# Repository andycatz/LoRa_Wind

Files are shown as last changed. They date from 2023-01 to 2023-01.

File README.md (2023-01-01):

# LoRa_Wind
Wind Sensor with LoRa transmitter
Code is for the PIC18LF46K22 microcontroller.
Data is transmitted as 50 bytes to the base receiver (Raspberry pi) running WSP2.py code.
See the file "Sensor Data Formats New Formats from 18th Sept 2021 onwards.xlsx".
Wind speed is derived by counting pulses, 2 per rotation assumed from sensor.
Gust is calculated by storing pulse count every 2 seconds.  After one minute, the highest count is stored for transmission as the gust speed.
The average speed is transmitted as the total pulse count for 1 minute.
All calibration is done at the receiver (Raspberry pi).
This module is powered from 2 x C size batteries which should last a good 2 to 3 years.
Make sure the battery housing is in an accessible location for battery change.
Alkaline batteries are recommended due to the wider temperature range of operation.
STL files are provided for the battery/transmitter enclosure.

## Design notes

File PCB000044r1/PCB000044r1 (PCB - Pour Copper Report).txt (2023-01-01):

Pour Copper Report
------------------

Report Written:     Saturday, January 29, 2022
Project Path:       D:\Documents\Design Spark\000000's\PCB000044r1\PCB000044r1.prj
Design Path:        D:\Documents\Design Spark\000000's\PCB000044r1\PCB000044r1.pcb
Design Title:       
Created:            03/01/2022 11:23:58
Last Saved:         29/01/2022 21:23:30
Editing Time:       291 min
Units:              mm (precision 1)

End Of Report.

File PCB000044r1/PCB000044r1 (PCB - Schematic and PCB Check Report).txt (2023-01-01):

Schematic and PCB Check Report
------------------------------

Report Written:     Saturday, January 29, 2022
Project Path:       D:\Documents\Design Spark\000000's\PCB000044r1\PCB000044r1.prj
Design Path:        D:\Documents\Design Spark\000000's\PCB000044r1\PCB000044r1.pcb
Design Title:       
Created:            03/01/2022 11:23:58
Last Saved:         29/01/2022 20:46:41
Editing Time:       260 min
Units:              mm (precision 1)

Checking integrity of Schematic and Pcb designs in project "PCB000044r1"
========================================================================

End Of Report.

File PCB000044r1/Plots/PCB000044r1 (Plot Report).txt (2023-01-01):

Plot Report
-----------

Report Written:     Sunday, January 30, 2022
Project Path:       D:\Documents\Design Spark\000000's\PCB000044r1\PCB000044r1.prj
Design Path:        D:\Documents\Design Spark\000000's\PCB000044r1\PCB000044r1.pcb
Design Title:       
Created:            03/01/2022 11:23:58
Last Saved:         29/01/2022 21:34:18
Editing Time:       304 min
Units:              mm (precision 3)

Device Settings
===============

Drill Settings
==============

    Excellon Format 2
    Format 3.5 absolute in mm.
    Zero suppression Leading

Plots Output
============

    Plot Job: "D:\Documents\Design Spark\000000's\PCB000044r1\PCB000044r1.mop"

NC Drill Output
===============

D:\Documents\Design Spark\000000's\PCB000044r1\Plots\PCB000044r1 - NC Drill Data - [Through Hole].nc

    Output:
    -----------------------------
    Plated Round Drill Holes
    Unplated Round Drill Holes
    Plated Slots
    Unplated Slots

    Tool  Size       Count   ID
    ----------------------------------
    T001  0.60000 mm 77    E
    T002  0.60960 mm 16    B
    T003  0.80000 mm 1     J
    T004  0.81280 mm 14    L
    T005  1.00000 mm 26    D
    T006  1.20000 mm 3     C
    T007  1.49860 mm 7     O
    T008  3.20000 mm 4     F
    ----------------------------------
    Total            148
    ----------------------------------

End Of Report.

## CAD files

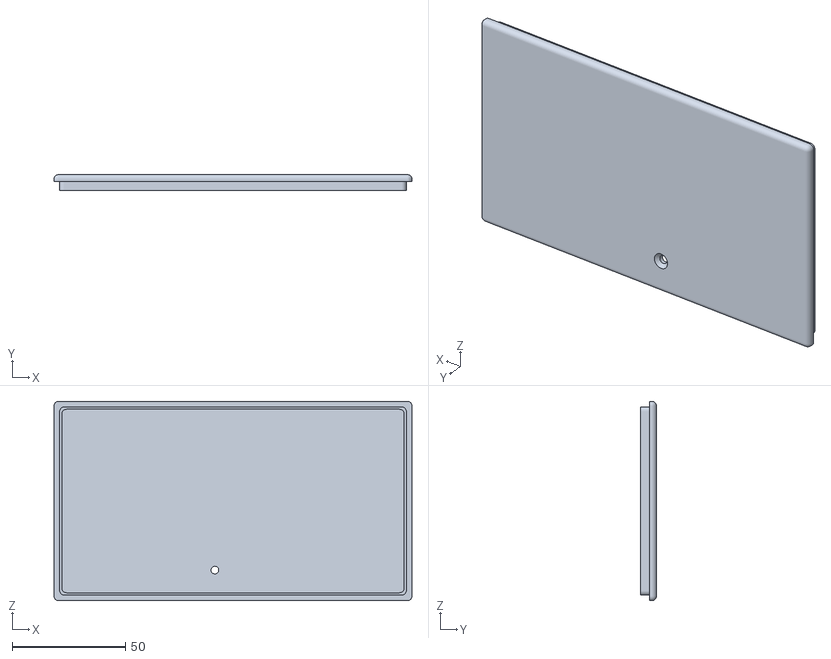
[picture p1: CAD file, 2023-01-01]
Wind Sensor Enclosure/Cover.stl
158.0 x 7.00 x 88.0

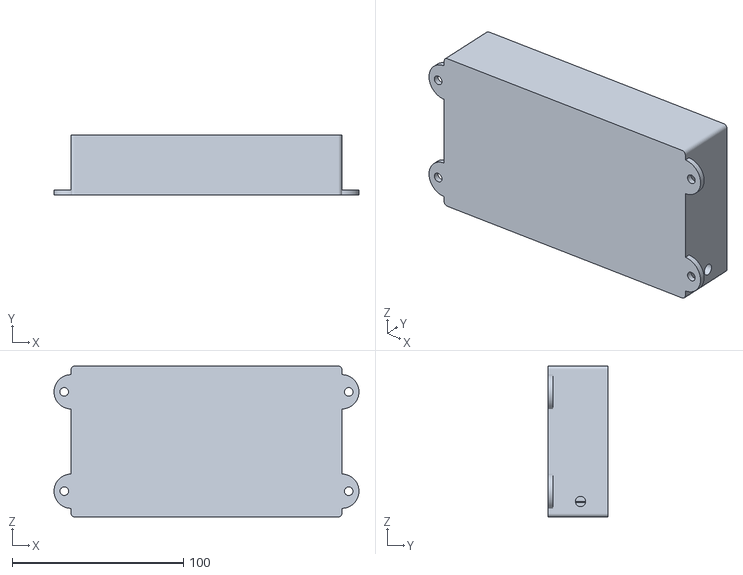
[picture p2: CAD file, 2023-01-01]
Wind Sensor Enclosure/Box.stl
178.0 x 35.0 x 88.0

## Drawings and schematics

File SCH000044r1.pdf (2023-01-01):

A | B | C | D | E | F

2

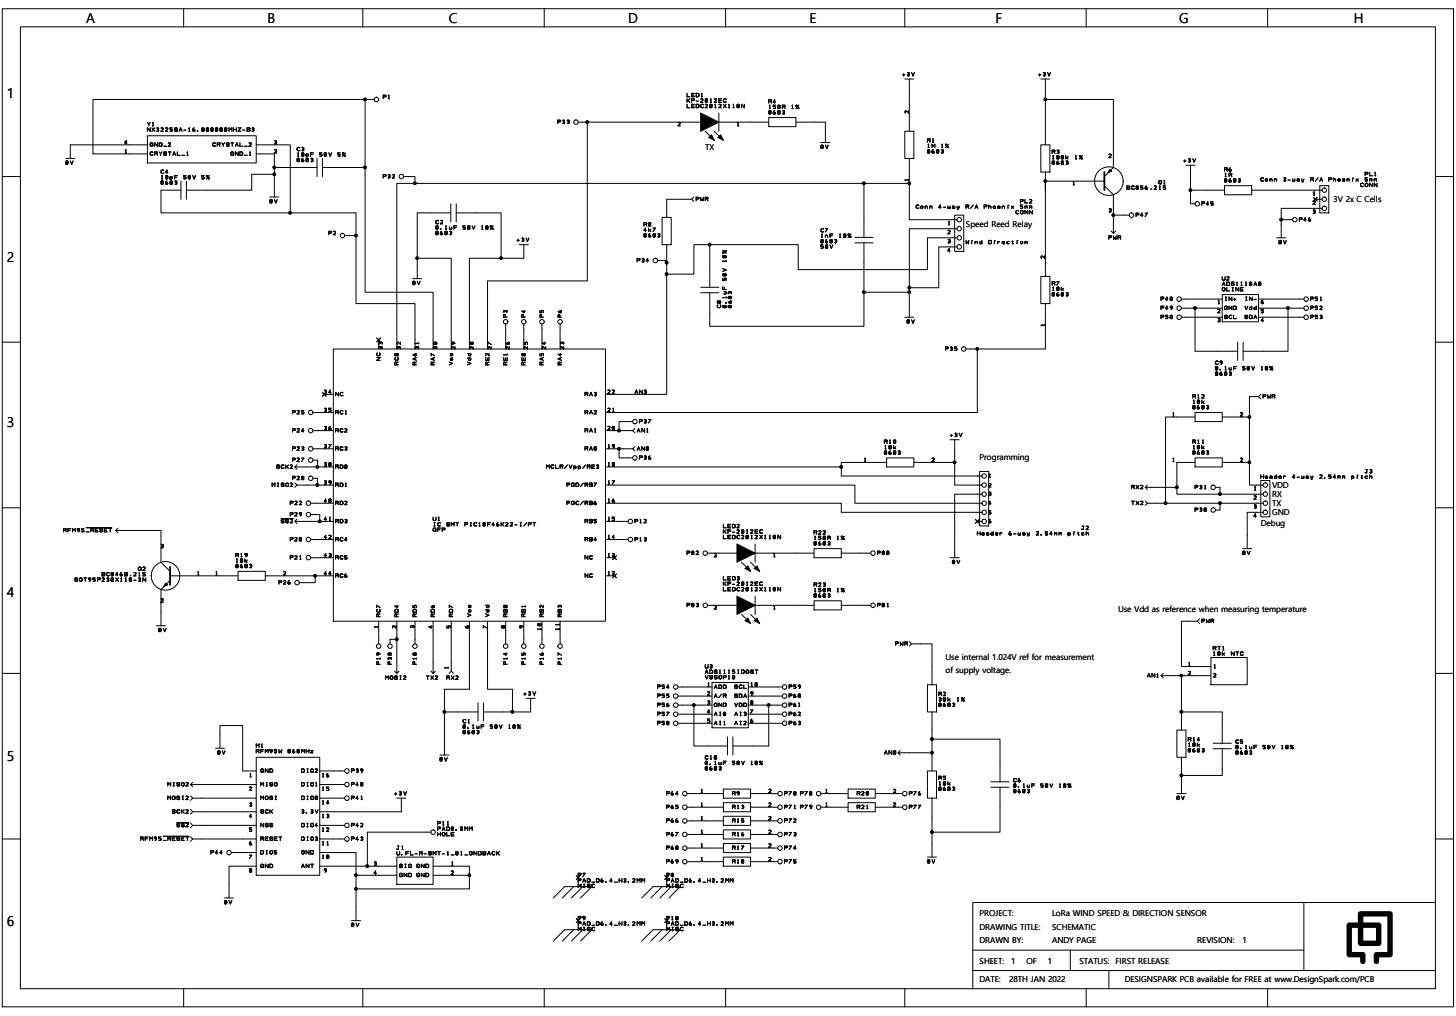
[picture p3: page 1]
28TH JAN 2022; Programming; Debug; VDD; GND; 3V 2x C Cells; PROJECT: DRAWING TITLE: DRAWN BY:; SHEET:; DATE:; REVISION:

Speed Reed Relay

Use Vdd as reference when measuring temperature

Use internal 1.024V ref for measurement
of supply voltage.

LoRa WIND SPEED & DIRECTION SENSOR
SCHEMATIC
ANDY PAGE
STATUS:

FIRST RELEASE
DESIGNSPARK PCB available for FREE at www.DesignSpark.com/PCB

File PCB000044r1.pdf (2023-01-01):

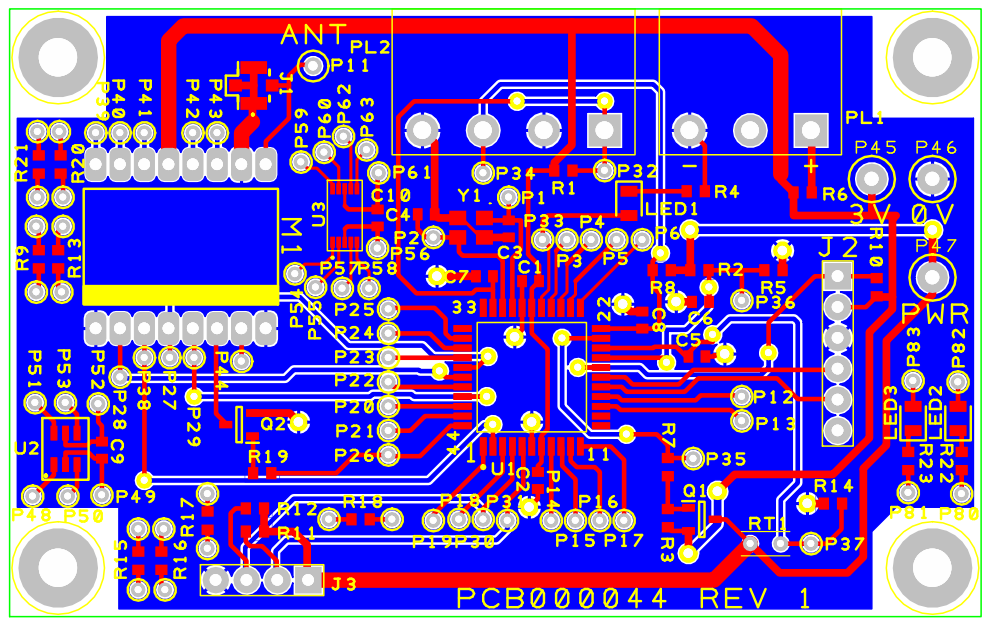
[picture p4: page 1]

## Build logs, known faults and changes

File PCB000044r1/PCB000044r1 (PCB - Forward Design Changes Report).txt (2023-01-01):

Forward Design Changes Report
-----------------------------

Report Written:     Saturday, January 29, 2022
Project Path:       D:\Documents\Design Spark\000000's\PCB000044r1\PCB000044r1.prj
Design Path:        D:\Documents\Design Spark\000000's\PCB000044r1\PCB000044r1.pcb
Design Title:       
Created:            03/01/2022 11:23:58
Last Saved:         29/01/2022 20:46:41
Editing Time:       260 min
Units:              mm (precision 1)

Added net "N0074".
Added net "N0075".
Added net "N0076".
Added net "N0077".
Added net "N0079".
Added net "N0080".
Added net "N0081".
Added net "N0082".
Added net "N0084".
Added net "N0085".
Added net "N0086".
Added net "N0087".
Added net "N0088".
Added net "N0089".
Added net "N0090".
Added net "N0091".
Added net "N0092".
Added net "N0093".
Added net "N0094".
Added net "N0095".
Added net "N0096".
Added net "N0097".
Added net "N0098".
Added net "N0099".
Added net "N0100".
Added net "N0101".
Added net "N0102".
Added net "N0103".
Added net "N0104".
Added net "N0105".
Added net "N0106".
Added net "N0107".

Added component reference "U3" of component "ADS1115IDGST", package "VSSOP10".
Added component reference "C10" of component "C0603C104K5RACTU", package "CAPC1608X95N".
Added value "Value=0.1uF 50V 10%" to component reference "C10".
Added value "Package=0603" to component reference "C10".
Added component reference "P54" of component "PAD0.6MM", package "PAD".
Added component reference "P55" of component "PAD0.6MM", package "PAD".
Added component reference "P56" of component "PAD0.6MM", package "PAD".
Added component reference "P57" of component "PAD0.6MM", package "PAD".
Added component reference "P58" of component "PAD0.6MM", package "PAD".
Added component reference "P59" of component "PAD0.6MM", package "PAD".
Added component reference "P60" of component "PAD0.6MM", package "PAD".
Added component reference "P61" of component "PAD0.6MM", package "PAD".
Added component reference "P62" of component "PAD0.6MM", package "PAD".
Added component reference "P63" of component "PAD0.6MM", package "PAD".
Added component reference "R9" of component "CRCW060310K0FKEAHP", package "RESC1608X50N".
Added component reference "R13" of component "CRCW060310K0FKEAHP", package "RESC1608X50N".
Added component reference "R15" of component "CRCW060310K0FKEAHP", package "RESC1608X50N".
Added component reference "R16" of component "CRCW060310K0FKEAHP", package "RESC1608X50N".
Added component reference "R17" of component "CRCW060310K0FKEAHP", package "RESC1608X50N".
Added component reference "R18" of component "CRCW060310K0FKEAHP", package "RESC1608X50N".
Added component reference "R20" of component "CRCW060310K0FKEAHP", package "RESC1608X50N".
Added component reference "R21" of component "CRCW060310K0FKEAHP", package "RESC1608X50N".
Added component reference "P64" of component "PAD0.6MM", package "PAD".
Added component reference "P65" of component "PAD0.6MM", package "PAD".
Added component reference "P66" of component "PAD0.6MM", package "PAD".
Added component reference "P67" of component "PAD0.6MM", package "PAD".
Added component reference "P68" of component "PAD0.6MM", package "PAD".
Added component reference "P69" of component "PAD0.6MM", package "PAD".
Added component reference "P70" of component "PAD0.6MM", package "PAD".
Added component reference "P71" of component "PAD0.6MM", package "PAD".
Added component reference "P72" of component "PAD0.6MM", package "PAD".
Added component reference "P73" of component "PAD0.6MM", package "PAD".
Added component reference "P74" of component "PAD0.6MM", package "PAD".
Added component reference "P75" of component "PAD0.6MM", package "PAD".
Added component reference "P76" of component "PAD0.6MM", package "PAD".
Added component reference "P77" of component "PAD0.6MM", package "PAD".
Added component reference "P78" of component "PAD0.6MM", package "PAD".
Added component reference "P79" of component "PAD0.6MM", package "PAD".
Added component reference "LED2" of component "KP-2012EC", package "LEDC2012X110N".
Added component reference "LED3" of component "KP-2012EC", package "LEDC2012X110N".
Added component reference "R22" of component "CRCW0603150RFKTA", package "RESC1608X50N".
Added value "Value=150R 1%" to component reference "R22".
Added value "Package=0603" to component reference "R22".
Added component reference "R23" of component "CRCW0603150RFKTA", package "RESC1608X50N".
Added value "Value=150R 1%" to component reference "R23".
Added value "Package=0603" to component reference "R23".
Added component reference "P80" of component "PAD0.6MM", package "PAD".
Added component reference "P81" of component "PAD0.6MM", package "PAD".
Added component reference "P82" of component "PAD0.6MM", package "PAD".
Added component reference "P83" of component "PAD0.6MM", package "PAD".

Connected pin "U3.1" to net "N0076".
Connected pin "U3.2" to net "N0077".
Connected pin "U3.3" to net "N0075".
Connected pin "U3.4" to net "N0079".
Connected pin "U3.5" to net "N0080".
Connected pin "U3.6" to net "N0085".
Connected pin "U3.7" to net "N0084".
Connected pin "U3.8" to net "N0074".
Connected pin "U3.9" to net "N0082".
Connected pin "U3.10" to net "N0081".
Connected pin "C10.1" to net "N0075".
Connected pin "C10.2" to net "N0074".
Connected pin "P54.1" to net "N0076".
Connected pin "P55.1" to net "N0077".
Connected pin "P56.1" to net "N0075".
Connected pin "P57.1" to net "N0079".
Connected pin "P58.1" to net "N0080".
Connected pin "P59.1" to net "N0081".
Connected pin "P60.1" to net "N0082".
Connected pin "P61.1" to net "N0074".
Connected pin "P62.1" to net "N0084".
Connected pin "P63.1" to net "N0085".
Connected pin "R9.1" to net "N0086".
Connected pin "R9.2" to net "N0092".
Connected pin "R13.1" to net "N0087".
Connected pin "R13.2" to net "N0093".
Connected pin "R15.1" to net "N0088".
Connected pin "R15.2" to net "N0094".
Connected pin "R16.1" to net "N0089".
Connected pin "R16.2" to net "N0095".
Connected pin "R17.1" to net "N0090".
Connected pin "R17.2" to net "N0096".
Connected pin "R18.1" to net "N0091".
Connected pin "R18.2" to net "N0097".
Connected pin "R20.1" to net "N0098".
Connected pin "R20.2" to net "N0100".
Connected pin "R21.1" to net "N0099".
Connected pin "R21.2" to net "N0101".
Connected pin "P64.1" to net "N0086".
Connected pin "P65.1" to net "N0087".
Connected pin "P66.1" to net "N0088".
Connected pin "P67.1" to net "N0089".
Connected pin "P68.1" to net "N0090".
Connected pin "P69.1" to net "N0091".
Connected pin "P70.1" to net "N0092".
Connected pin "P71.1" to net "N0093".
Connected pin "P72.1" to net "N0094".
Connected pin "P73.1" to net "N0095".
Connected pin "P74.1" to net "N0096".
Connected pin "P75.1" to net "N0097".
Connected pin "P76.1" to net "N0100".
Connected pin "P77.1" to net "N0101".
Connected pin "P78.1" to net "N0098".
Connected pin "P79.1" to net "N0099".
Connected pin "LED2.1" to net "N0103".
Connected pin "LED2.2" to net "N0102".
Connected pin "LED3.1" to net "N0105".
Connected pin "LED3.2" to net "N0104".
Connected pin "R22.1" to net "N0103".
Connected pin "R22.2" to net "N0106".
Connected pin "R23.1" to net "N0105".
Connected pin "R23.2" to net "N0107".
Connected pin "P80.1" to net "N0106".
Connected pin "P81.1" to net "N0107".
Connected pin "P82.1" to net "N0102".
Connected pin "P83.1" to net "N0104".

End Of Report.

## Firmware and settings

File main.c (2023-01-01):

/*
 * LoRa Wind Version 2
 * 9th January 2022
 * Version 2 attempts to get the standby current down really low to save
 * battery life.
 * File:   main.c
 * Author: andym
 *
 * Created on 09 January 2022, 11:18
 * Trace reduction in current:
 * Just SLEEP() with standard config.h, 2s watchdog, 64MHz crystal osc.  1.67mA
 * 337µA after turning off all peripherals and putting LoRa module into sleep mode with 16MHz crystal osc.
 * 29µA in wind tacho pull up 100k - change to 1M - need to check if tacho will still work after this.  Now 6uA if tacho in "ON" position
 * 333µA now.  What's left in the wrong state or turned on?
 * 48µA after setting RB1 high on PCB000040 (10k pullup to permanent 3V supply) Wanders around between 38uA and 52uA
 * 
 * 11th February 2022, 19:23 - Now on PCB000044 REV 1
 * 3µA steady current achieved without LoRa module fitted - just sleeping with everything shutdown.
 * 20:54: Now achieved 0 to 1µA (almost unmeasurable) by making sure programming pins are set as outputs and set low.
 * Otherwise these gradually float up after the programmer is removed, drawing 15µA or more after 30 minutes.
 * 22:00: Still <=1µA with LoRa module installed and set to sleep (1.5mA if you don't talk to it and put it to sleep).
 * 
 */


#include <xc.h>
#include "config.h"
#include "LoRa.h"

#define TX_FREQ 866.5
#define SYNC_WORD 0x55

void shutdown(void); //Shuts everything non-essential down to minimise power consumption.

void main(void) {
    OSCCONbits.IRCF=0b111; //Set internal clock to 16MHz
    OSCCONbits.OSTS=0; //Device is running from internal oscillator
    OSCCON2bits.PLLRDY=1; //System clock comes from 4xPLL
    OSCTUNEbits.PLLEN=1;//Enable PLL
    LoRaReset();
    LoRaStart(TX_FREQ, SYNC_WORD);
    __delay_ms(10);
    LoRaSleepMode();
    __delay_ms(10);
    shutdown();
    while(1){
        SLEEP();
        LATEbits.LE2=1; //Turn LED on
        __delay_ms(50);
        LATEbits.LE1=1;
        __delay_ms(50);
        LATEbits.LE0=1;
        __delay_ms(50);
        LATEbits.LE0=0;
        LATEbits.LE1=0;
        LATEbits.LE2=0; //Turn LED off again
    }
    
}

void shutdown(){
    //PORT A
    TRISAbits.RA0=0; //A0 is an output
    LATAbits.LA0=0; //Set to 0
    ANSELAbits.ANSA0=0; //Turn off analog input
    TRISAbits.RA1=0;
    LATAbits.LA1=0;
    ANSELAbits.ANSA1=0; //Turn off analog input
    TRISAbits.RA2=0; //A2 is an output
    LATAbits.LA2=1; //Set high to turn off PNP transistor
    ANSELAbits.ANSA2=0; //Turn off analog input
    TRISAbits.RA3=0; //A3 is an output
    LATAbits.LA3=0; //Set to 0
    ANSELAbits.ANSA3=0; //Turn off analog input
    TRISAbits.RA4=0; //A4 is an output
    LATAbits.LA4=0; //Set to 0
    //No analog on this port pin
    TRISAbits.RA5=0; //A5 is an output
    LATAbits.LA5=0; //Set to 0
    ANSELAbits.ANSA5=0; //Turn off analog input
    TRISAbits.RA6=0; //A6 is an output
    LATAbits.LA6=0; //Set to 0

    TRISAbits.RA7=0; //A5 is an output
    LATAbits.LA7=0; //Set to 0
    
    
    //PORT B
    LATBbits.LB0=0;
    TRISBbits.RB0=0;
    ANSELBbits.ANSB0=0;
    LATBbits.LB1=1; //Set high as 10k pullup to 3V on PCB000040
    TRISBbits.RB1=0;
    ANSELBbits.ANSB1=0;
    LATBbits.LB2=0;
    TRISBbits.RB2=0;
    ANSELBbits.ANSB2=0;
    LATBbits.LB3=0;
    TRISBbits.RB3=0;
    ANSELBbits.ANSB3=0;
    LATBbits.LB4=0;
    TRISBbits.RB4=0;
    ANSELBbits.ANSB4=0;
    LATBbits.LB5=0;
    TRISBbits.RB5=0;
    ANSELBbits.ANSB5=0;
    LATBbits.LB6=0;
    TRISBbits.RB6=0;
    LATBbits.LB7=0;
    TRISBbits.RB7=0;
    
    //PORT C
    LATCbits.LC0=0; //Input for wind tacho signal
    
    LATCbits.LC1=0;
    //No analogue on C0 or C1
    TRISCbits.RC1=0;
    
    LATCbits.LC2=0;
    TRISCbits.RC2=0;
    ANSELCbits.ANSC2=0;
    
    LATCbits.LC3=0;
    TRISCbits.RC3=0;
    ANSELCbits.ANSC3=0;
    
    LATCbits.LC4=0;
    TRISCbits.RC4=0;
    ANSELCbits.ANSC4=0;
    
    LATCbits.LC5=0;
    TRISCbits.RC5=0;
    ANSELCbits.ANSC5=0;
    
    LATCbits.LC6=0;
    TRISCbits.RC6=0;
    ANSELCbits.ANSC6=0;
    
    LATCbits.LC7=0;
    TRISCbits.RC7=0;
    ANSELCbits.ANSC7=0;
    
    //PORT D
    TRISDbits.RD0=0;
    LATDbits.LD0=0; //Leave high (SPI SCK)
    ANSELDbits.ANSD0=0; //Turn off analog
    
    TRISDbits.RD1=1; //Leave as an input (SPI MISO)
    //LATDbits.LD1=0;
    ANSELDbits.ANSD1=0; //Turn off analog
    
    TRISDbits.RD2=0;
    LATDbits.LD2=0;
    ANSELDbits.ANSD2=0; //Turn off analog
    
    TRISDbits.RD3=0; //Output
    LATDbits.LD3=1; //CS for SPI set to 1 to deselect LoRa device
    ANSELDbits.ANSD3=0; //Turn off analog
    
    TRISDbits.RD4=0; //Output
    LATDbits.LD4=0; //Leave high (SPI MOSI)
    ANSELDbits.ANSD4=0; //Turn off analog
    
    TRISDbits.RD5=0; //Output
    LATDbits.LD5=0;
    ANSELDbits.ANSD5=0; //Turn off analog
    
    TRISDbits.RD6=0; //Output
    LATDbits.LD6=0;
    ANSELDbits.ANSD6=0; //Turn off analog
    
    TRISDbits.RD7=0; //Output
    LATDbits.LD7=0;
    ANSELDbits.ANSD7=0; //Turn off analog
    
    //PORT E
    TRISEbits.RE0=0; //E0 is an output
    LATEbits.LE0=0; //Set to 0
    ANSELEbits.ANSE0=0; //Turn off analogue
    TRISEbits.RE1=0;
    LATEbits.LE1=0;
    ANSELEbits.ANSE1=0; //Turn off analogue
    TRISEbits.RE2=0; //Red LED is on this pin connected to ground via 150R resistor.
    LATEbits.LE2=0;
    ANSELEbits.ANSE2=0; //Turn off analogue
    
    //Peripherals
    ADCON0bits.ADON=0; //Turn off A to D module
    VREFCON0bits.FVREN=0; //Disable internal reference
    PMD0bits.UART2MD=1; //Turn off UART2
    PMD0bits.UART1MD=1; //Turn off UART1
    PMD0bits.TMR6MD=1; //Turn off timer 6
    PMD0bits.TMR5MD=1; //Turn off timer 5
    PMD0bits.TMR4MD=1; //Turn off timer 4
    PMD0bits.TMR3MD=1; //Turn off timer 3
    PMD0bits.TMR2MD=1; //Turn off timer 2
    PMD0bits.TMR1MD=1; //Turn off timer 1
    
    PMD0bits.SPI2MD=1; //Turn off SPI2
    PMD0bits.SPI1MD=1; //Turn off SPI1
    PMD0=0xFF; //Turn off all peripherals in PMD0 (UARTS, SPI)
    PMD1=0xFF; //Turn off all peripherals in PMD1 (including MSSP2 for SPI2)
    PMD2=0xFF; //Turn off all peripherals in PMD2 (ADC, comparators, CTMU)
}

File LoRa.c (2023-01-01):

#include <xc.h>
#include "LoRa.h"
#include <stdint.h>
#include <stdio.h>

#define DEBUG 1

/**
 * Configures PIC and LoRa module to start with specified frequency in MHz
 * from PIC18F46K22_LoRA_UVVIS_V2
 */
void LoRaStart(float freq, uint8_t syncWord){
    printf("LoRa Start\r\n");
    //Configure pin for LoRa module reset
    ANSELAbits.ANSA2=0; //Digital output buffer enabled (analogue function turned off)
    
    //Configure SPI2 as master
    //Set up SPI pins first
    TRISDbits.RD1=1; //SDIx must have corresponding TRIS bit set (input)
    TRISDbits.RD4=0; //SDOx must have corresponding TRIS bit cleared (output)
    TRISDbits.RD0=0; //SCKx (Master mode) must have corresponding TRIS bit cleared (output)
    TRISDbits.RD3=0; //#SS must have corresponding TRIS bit cleared (output)
    ANSELDbits.ANSD1=0; //Input buffer enabled
    ANSELDbits.ANSD4=0; //Digital
    ANSELDbits.ANSD3=0; //Digital
    ANSELDbits.ANSD0=0; //Digital
    LATDbits.LATD3=1; //Set SS high so chip is not selected
    
    PMD1bits.MSSP2MD=0; //Turn on MSSP2 module (SPI2)
    PMD0bits.SPI2MD=0; //Turn on SPI2
    
    
    //Clock polarity
    SSP2CON1bits.CKP=0; //Clock idle low, active high
    SSP2STATbits.CKE=1; //Active to idle 1
    
    //Input data sampling
    SSP2STATbits.SMP=1; //Input data sampled at end of data output time 1
    
    //SPI Mode and clock
    SSP2CON1bits.SSPM=0b0010; //SPI Master Mode, clock = Fosc/64
    
    //SPI Enable
    SSP2CON1bits.SSPEN=1; //Enabled
    
    //LoRaReset();
    if(DEBUG){
        printf("Set LoRa Mode\r\n");
    }
    __delay_ms(10);
    setLoRaMode();
    __delay_ms(10);
    if(DEBUG){
        printf("LoRa load optimal register values\r\n");
    }
    LoRaOptimalLoad(syncWord);
    if(DEBUG){
        printf("LoRa set frequency\r\n");
    }
    LoRaSetFrequency(freq); //Can only set in standby or sleep modes
}

uint8_t LoRaGetVersion(){
    uint8_t temp = SPI2ReadByte(VERSION_REG);
    return temp;
}

void LoRaReset(){
    //Perform reset
    TRISAbits.RA2=0; //Configure port as an output
    LATAbits.LA2=0; //In reset
    __delay_ms(1);
    TRISAbits.RA2=1; //Configure port as input (goes high-Z)
    __delay_ms(5);
}

void setLoRaMode(){
    //Set Long Range Mode bit in OpMode register
    uint8_t regValue = readOpModeRegister();
    regValue = regValue | LORA_MODE; //Set bit 7 high and leave others as is
    writeOpModeRegister(regValue); //Write the value back
}

uint8_t readOpModeRegister(){
    return SPI2ReadByte(OP_MODE_REG);
}

void writeOpModeRegister(uint8_t regValue){
    SPI2WriteByte(OP_MODE_REG, regValue);
}



void LoRaMode_RXActive(){
    SPI2WriteByte(OP_MODE_REG, 0b1000101); //LoRa Mode with Receiver active all the time
}

/**
 * SPI2WriteByte
 * Writes an address byte, then writes a data byte
 * @param address
 * @param data
 */
void SPI2WriteByte(uint8_t address, uint8_t data){
    SSP2IF=0; //Clear interrupt flag
    LATDbits.LATD3=0; //Set SS low
    __delay_us(5);
    address = address|0x80; //bit 7 set to indicate a register write
    SSP2BUF=address; //Write address to SPI buffer 
    while(!SSP2IF){
        //Wait for transmission to complete
    }
    SSP2IF=0; //Clear interrupt flag
    __delay_us(5);
    SSP2BUF=data; 
    while(!SSP2IF){
        //Wait for transmission and reception to complete
    }
    __delay_us(5);
    LATDbits.LATD3=1; //Set SS high
    SSP2IF=0; //Clear interrupt flag
    uint8_t dataByte = SSP2BUF; //A byte has been received but this is not used.
}

/**
 * SPI2ReadByte
 * Writes an address byte then reads a byte back.  0 is sent as a dummy value
 * for the second transfer.
 * @param address
 * @return 
 */
uint8_t SPI2ReadByte(uint8_t address){
    SSP2IF=0; //Clear interrupt flag
    LATDbits.LATD3=0; //Set SS low
    SSP2BUF=address; //Write data to SPI buffer
    while(!SSP2IF){
        //Wait for transmission to complete
    }
    SSP2IF=0; //Clear interrupt flag
    SSP2BUF=0; //Data byte - for a read, set to 0
    while(!SSP2IF){
        //Wait for transmission and reception to complete
    }
    SSP2IF=0; //Clear interrupt flag
    //__delay_us(20);
    LATDbits.LATD3=1; //Set SS high
    uint8_t dataByte = SSP2BUF;
    return dataByte;
}

/* 
 * Transmits a data packet.
 */
void LoRaTXData(uint8_t* data, uint8_t dataLength){
    //Must be in standby mode for this to work
    LoRaStandbyMode();
    printf("Transmitting.\r\n");
    SPI2WriteByte(FIFO_ADD_PTR_REG, 0);
    SPI2WriteByte(PAYLOAD_LENGTH_REG, 0);
    

    for(uint8_t i=0;i<dataLength;i++){
        SPI2WriteByte(FIFO_REG, data[i]);
    }
    SPI2WriteByte(PAYLOAD_LENGTH_REG, dataLength);
    LoRaTXMode(); //Set TX mode to send the message
    
    //Will return to standby mode automatically when finished.
    //You can check TxDone interrupt to see if it's finished.
}

/**
 * Sets the LoRa module into standby mode
 */
void LoRaStandbyMode(){
    uint8_t regValue = readOpModeRegister(); //Read whats in there already
    regValue = regValue & 0b11111000; //Blank out other modes
    regValue = regValue | STANDBY_MODE; //Set bit 0 high and leave others as is
    writeOpModeRegister(regValue); //Write the value back
}

void LoRaSleepMode(){
    uint8_t regValue = readOpModeRegister(); //Read whats in there already
    regValue = regValue & 0b11111000; //Blank out other modes
    regValue = regValue | SLEEP_MODE;
    writeOpModeRegister(regValue); //Write the value back
}

void LoRaFreqSynthRXMode(){
    uint8_t regValue = readOpModeRegister(); //Read whats in there already
    regValue = regValue & 0b11111000; //Blank out other modes
    regValue = regValue | FREQ_SYNTH_RX_MODE; //Set bit 0 high and leave others as is
    writeOpModeRegister(regValue); //Write the value back
}

void LoRaFreqSynthTXMode(){
    uint8_t regValue = readOpModeRegister(); //Read whats in there already
    regValue = regValue & 0b11111000; //Blank out other modes
    regValue = regValue | FREQ_SYNTH_TX_MODE; //Set bit 0 high and leave others as is
    writeOpModeRegister(regValue); //Write the value back
}

void LoRaTXMode(){
    printf("TX Mode\r\n");
    uint8_t regValue = readOpModeRegister(); //Read whats in there already
    regValue = regValue & 0b11111000; //Blank out other modes
    regValue = regValue | TX_MODE; //Set bit 0 high and leave others as is
    writeOpModeRegister(regValue); //Write the value back
}

void LoRaRXContinuousMode(){
    uint8_t regValue = readOpModeRegister(); //Read whats in there already
    regValue = regValue & 0b11111000; //Blank out other modes
    regValue = regValue | RX_CONT_MODE; //Set bit 0 high and leave others as is
    writeOpModeRegister(regValue); //Write the value back02
}
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

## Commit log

2023-01-01 Add files via upload
    Original project files.
    [PCB000044r1 - Documentation.gbr, PCB000044r1 - Drill Ident Drawing - [Through Hole].gbr, PCB000044r1 - Gerber Drill Data - [Through Hole].gbr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]
2023-01-01 Add files via upload
    Added STL (3D printer) files for the transmitter/battery enclosure.
    [Box.stl, Cover.stl]
